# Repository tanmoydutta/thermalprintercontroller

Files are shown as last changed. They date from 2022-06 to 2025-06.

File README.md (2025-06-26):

<h1>Thermal Printer Controller Hardware</h1>

Anthe is a Wireless Thermal Printer controller over WiFi and Bluetooth. It is based on ESP32-C3-FH4 Microcontroller. 

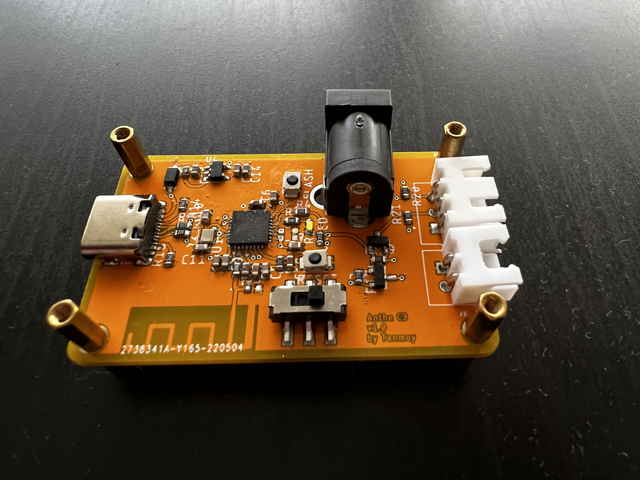
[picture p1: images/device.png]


Features include - 
- Programmable WiFi and Bluetooth Connectivity for Thermal Printer
- Onboard logic level shifter for 5V Printer operation.
- Onboard Printer power supply connector
- USB-C Port for programming
- Onboard programmable RGB and normal LED indicators
- Onboard WiFi and Bluetooth Antenna
- Compact size 
- Powered by ESP32-C3-FH4 Microcontroller

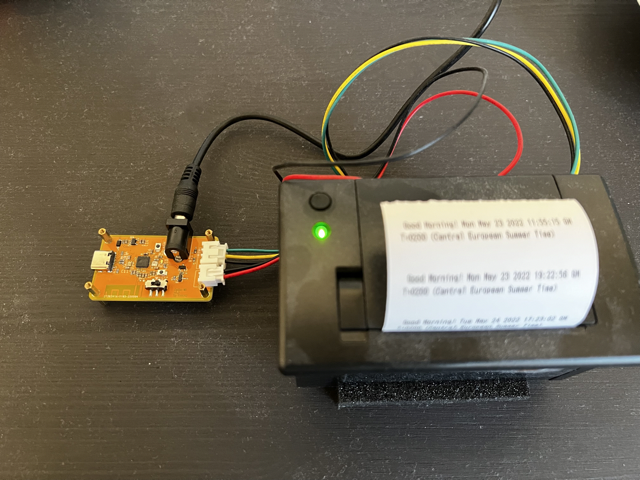
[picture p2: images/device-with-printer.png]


Build your own Printer driver using Adafruit Thermal Printer library and extend connectivity over WiFi and Bluetooth.

This is an OSHWA certified hardware - 
<p align="center">
  <a href="https://certification.oshwa.org/nl000031.html">
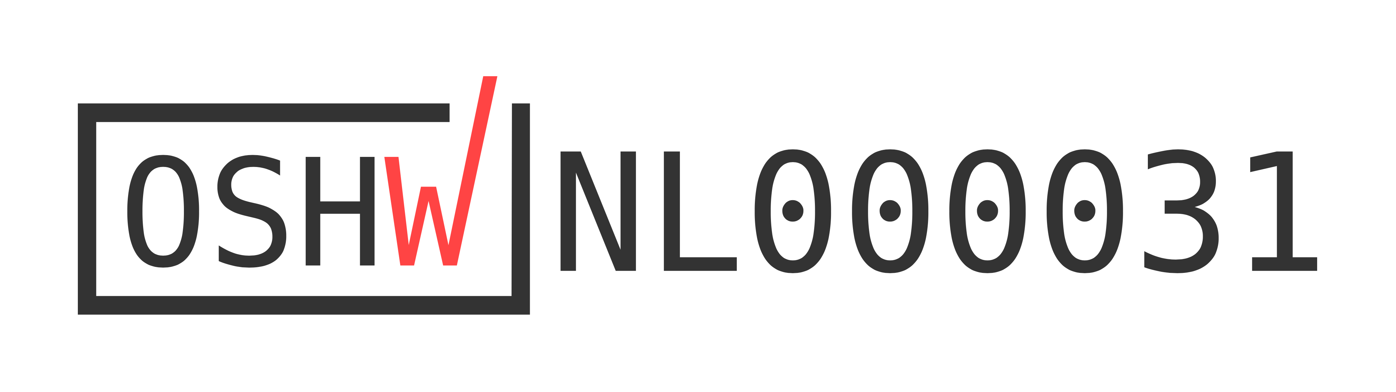
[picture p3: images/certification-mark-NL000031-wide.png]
OSHWA OSHWA Certification
    
  </a>
</p>



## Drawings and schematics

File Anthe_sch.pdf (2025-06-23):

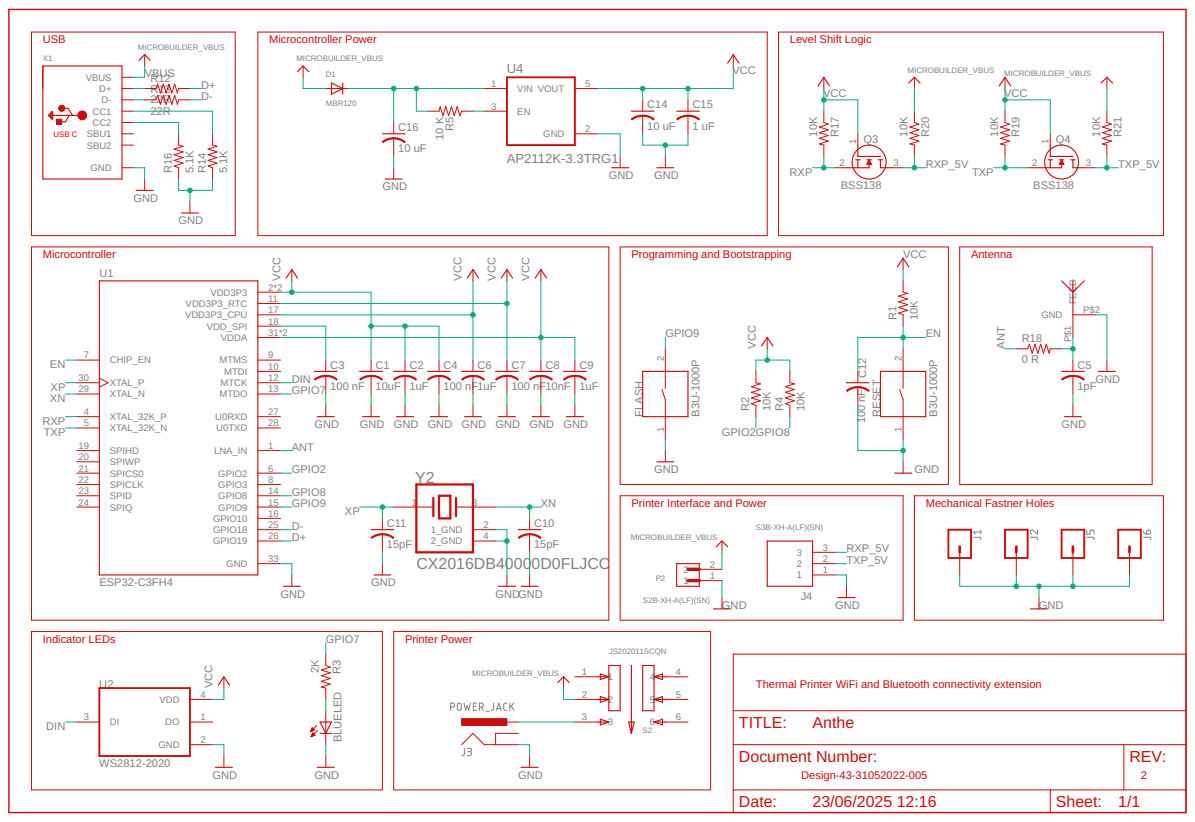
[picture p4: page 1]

GND GND

Document Number: | REV:

Date: 23/06/2025 12:16 | Sheet: 1/1

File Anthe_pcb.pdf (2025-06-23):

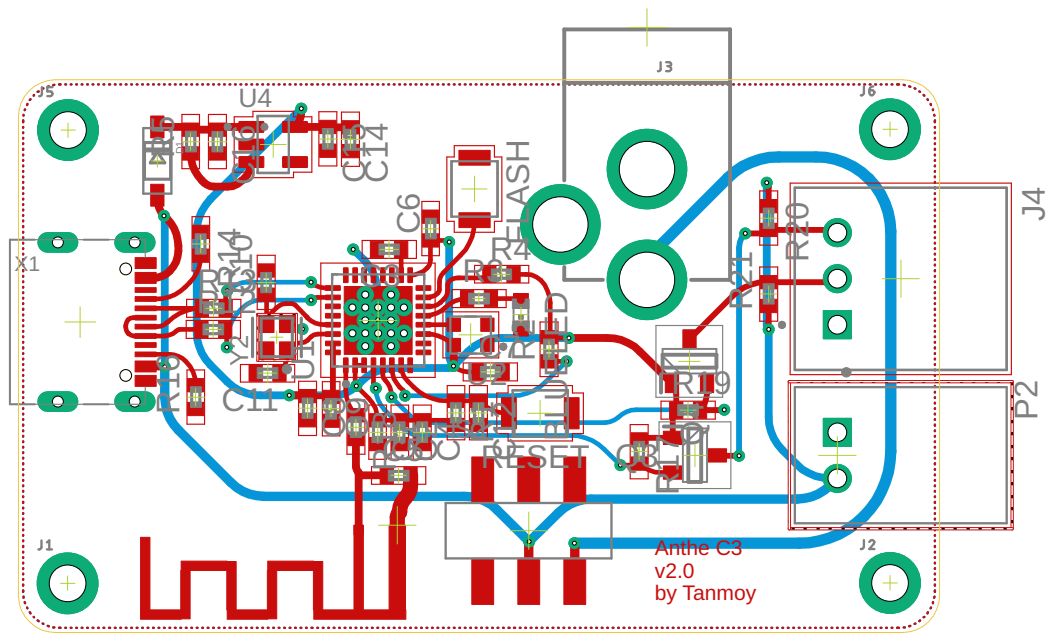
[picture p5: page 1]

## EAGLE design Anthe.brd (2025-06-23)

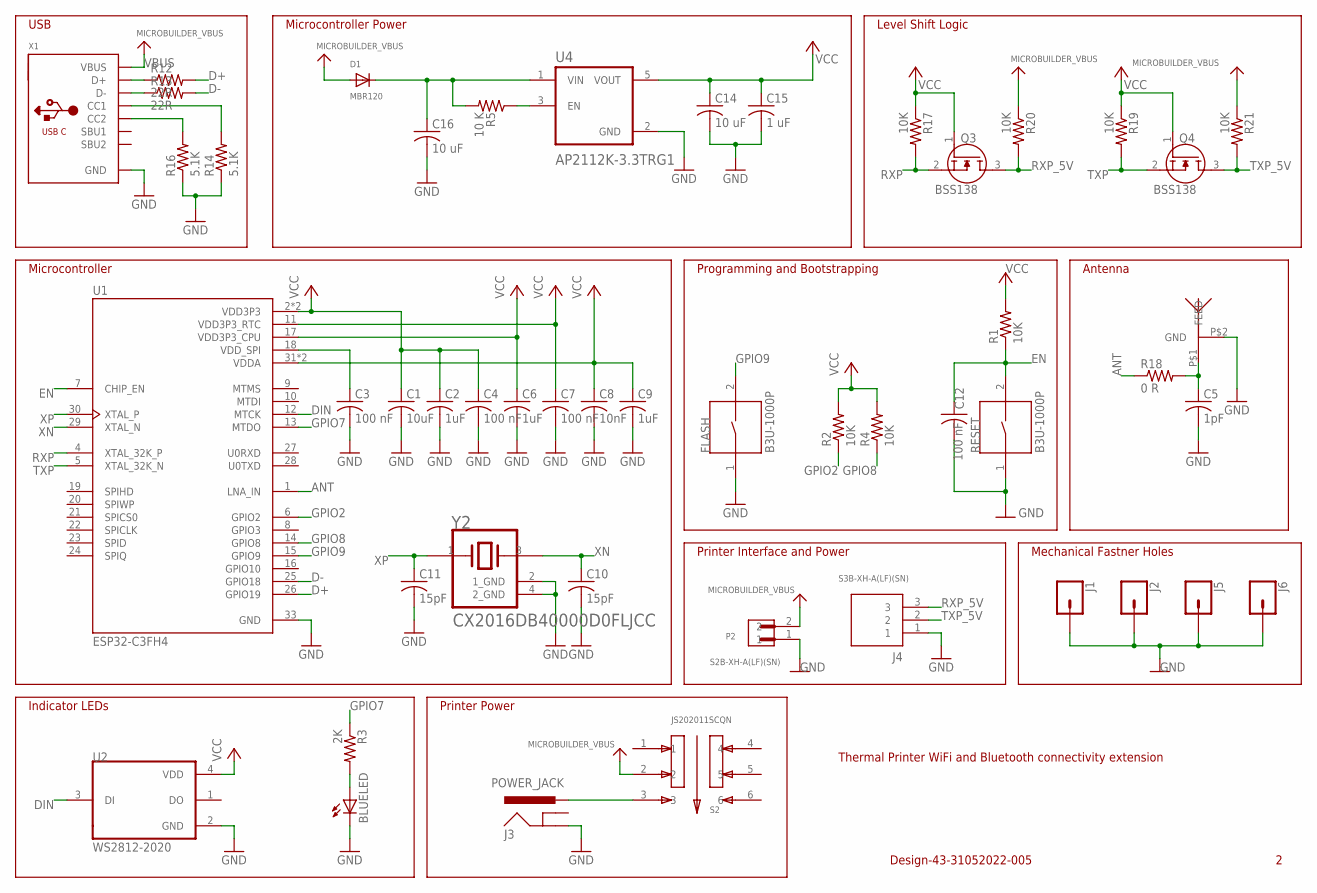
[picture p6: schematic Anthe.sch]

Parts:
BLUELED: LEDCHIPLED_0603; CHIPLED_0603
C1: 10uF; C0402
C2, C6, C9: 1uF; C0402
C3, C4, C7, C12: 100 nF; C0402
C5: 1pF; C0402
C8: 10nF; C0402
C10, C11: 15pF; C0402
C14, C16: 10 uF; C0402
C15: 1 uF; C0402
D1: MBR120; SOD-123
FLASH: B3U-1000P; SW_B3U-1000P
J1, J2, J5, J6: CONN_01PTH_2MM; 1X01_2MM
J3: POWER_JACK; POWER_JACK_PTH
J4: S3B-XH-A(LF)(SN); JST_S3B-XH-A(LF)(SN)
P2: S2B-XH-A(LF)(SN); JST_S2B-XH-A(LF)(SN)
Q3, Q4: BSS138; SOT95P240X120-3N
R1, R2, R4, R17, R19, R20, R21: 10K; R0402
R3: 2K; R0402
R5: 10 K; R0402
R12, R13: 22R; R0402
R14, R16: 5.1K; R0402
R18: 0 R; R0402
RESET: B3U-1000P; SW_B3U-1000P
S2: JS202011SCQN; SW_JS202011SCQN
U1: ESP32-C3FH4; QFN50P500X500X90-33N
U2: WS2812-2020; LED_WS2812-2020
U4: AP2112K-3.3TRG1; SOT95P285X140-5N
U$3: PCB_ANTENNA_WIFI; WIFI_ANTENNA
X1: MICROBUILDER_USB_C; MICROBUILDER_USB_C_CUSB31-CFM2AX-01-X
Y2: KYOCERA_INTERNATIONAL_INC._ELECTRONIC_COMPONENTS_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; KYOCERA_INTERNATIONAL_INC._ELECTRONIC_COMPONENTS_CX2016DB40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

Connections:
ANT: R18.1, U1.1 (LNA_IN)
D+: R12.2, U1.26 (GPIO19)
D-: R13.2, U1.25 (GPIO18)
DIN: U1.12 (MTCK), U2.3 (DI)
EN: C12.1, R1.1, RESET.2, U1.7 (CHIP_EN)
GND: BLUELED.C, C1.2, C2.2, C3.2, C4.2, C5.2, C6.2, C7.2, C8.2, C9.2, C10.2, C11.2, C12.2, C14.2, C15.2, C16.2, FLASH.1, J1.1, J2.1, J3.GND, J4.1, J5.1, J6.1, P2.1, R14.1, R16.1, RESET.1, U1.33 (GND), U2.2 (GND), U4.2 (GND), U$3.P$2 (GND), X1.A1B12 (GND), X1.B1A12 (GND), Y2.2 (1_GND), Y2.4 (2_GND)
GPIO2: R2.1, U1.6 (GPIO2)
GPIO7: R3.1, U1.13 (MTDO)
GPIO8: R4.1, U1.14 (GPIO8)
GPIO9: FLASH.2, U1.15 (GPIO9)
unnamed: J3.PWR, S2.3
unnamed: C5.1, R18.2, U$3.P$1 (FEED)
unnamed: C3.1, U1.18 (VDD_SPI)
unnamed: BLUELED.A, R3.2
unnamed: R12.1, X1.A6 (D+), X1.B6 (D+)
unnamed: C16.1, D1.C, R5.2, U4.1 (VIN)
unnamed: R13.1, X1.A7 (D-), X1.B7 (D-)
unnamed: R14.2, X1.A5 (CC1)
unnamed: R16.2, X1.B5 (CC2)
unnamed: R5.1, U4.3 (EN)
RXP: Q3.2 (S), R17.2, U1.4 (XTAL_32K_P)
RXP_5V: J4.3, Q3.3 (D), R20.2
TXP: Q4.2 (S), R19.2, U1.5 (XTAL_32K_N)
TXP_5V: J4.2, Q4.3 (D), R21.2
VBUS: D1.A, P2.2, R20.1, R21.1, S2.2, X1.A4B9 (VBUS), X1.B4A9 (VBUS)
VCC: C1.1, C2.1, C4.1, C6.1, C7.1, C8.1, C9.1, C14.1, C15.1, Q3.1 (G), Q4.1 (G), R1.2, R2.2, R4.2, R17.1, R19.1, U1.2 (VDD3P3), U1.3 (VDD3P3), U1.11 (VDD3P3_RTC), U1.17 (VDD3P3_CPU), U1.31 (VDDA), U1.32 (VDDA), U2.4 (VDD), U4.5 (VOUT)
XN: C10.1, U1.29 (XTAL_N), Y2.3
XP: C11.1, U1.30 (XTAL_P), Y2.1

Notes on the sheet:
USB
Microcontroller Power
Microcontroller
Level Shift Logic
Programming and Bootstrapping
Antenna
Indicator LEDs
Thermal Printer WiFi and Bluetooth connectivity extension
Design-43-31052022-005
Printer Power
Printer Interface and Power
Mechanical Fastner Holes

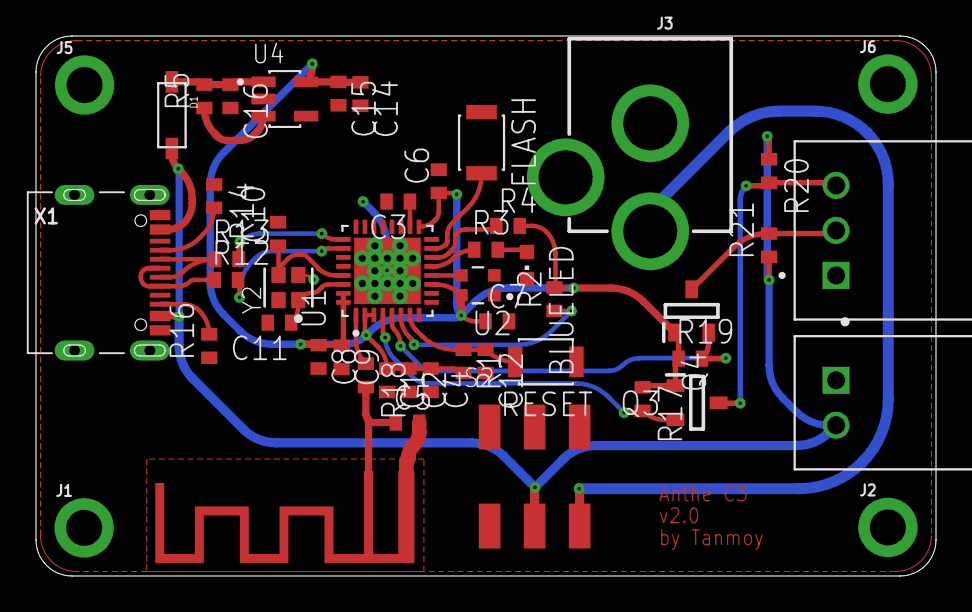
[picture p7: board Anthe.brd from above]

Board: 2 copper layers, 50.0 x 30.0 mm, 49 parts (0 on the bottom side), 28 nets.

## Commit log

2022-06-01 Add files via upload
    EAGLE schematics and PCB board files. PDF version of schematics and board design file.
    [Anthe.brd, Anthe.sch]
2025-06-23 File updates to design
    [Anthe.brd, Anthe.sch]

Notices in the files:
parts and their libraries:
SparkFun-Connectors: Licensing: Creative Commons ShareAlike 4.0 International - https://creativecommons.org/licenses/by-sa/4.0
